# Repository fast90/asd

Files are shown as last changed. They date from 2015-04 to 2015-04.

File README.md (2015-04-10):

#Audio Switch Daemon

This circuit switches two audio sources, based on the status of a MPD-server running on a Raspberry Pi.

If MPD is playing the Raspberry Pi (INPUT 2) is switched to OUT.
When MPD stops playing OUT is switched back to INPUT 1.

# Library
Libbcm2835 is used for GPIO access. See http://www.airspayce.com/mikem/bcm2835/ for details.

# Schematic
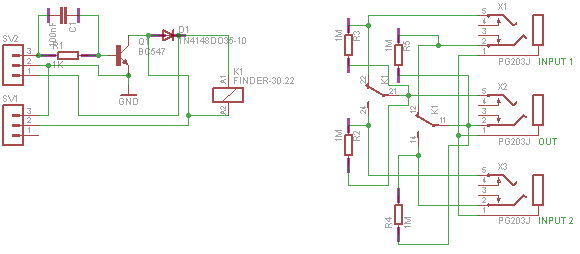
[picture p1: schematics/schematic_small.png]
Schematic


# Wiring
| Raspberry Pi Pin No. | Audioswitch Pin | Function |
|:---:|:---:|:---:|
| 8 | SV2 - 3 | GPIO 14  |
| 2 | SV2 - 2 | GND |
| 6 | SV2 - 1 | +5V |

SV1 can be used to connect a manual switch.

# Setup
Install the Library see http://www.airspayce.com/mikem/bcm2835/ for details.

If you are using a Raspberry Pi 2 you need to enable device tree support!

```bash
sudo raspi-config
```
```bash
->Advanced Options -> enable Device Tree
sudo shutdown -r now
```
Then type
```bash
./configure
make
make install
```

# Configuration & Usage
|  Option | Argument | Function | Default |
|:---:|:---:|:---:|:---|
|  h | |Show help | |
|  v | |Show version | |
| no-daemon | |Don't detach from console | |
|  p | <PinNumber>  |Change Pin | GPIO17 |
|  s | <SocketPath> |Change Path to socket |/home/pi/.mpd/socket|

```bash
asd -p 17 -s /home/user/.mpd/sock
```

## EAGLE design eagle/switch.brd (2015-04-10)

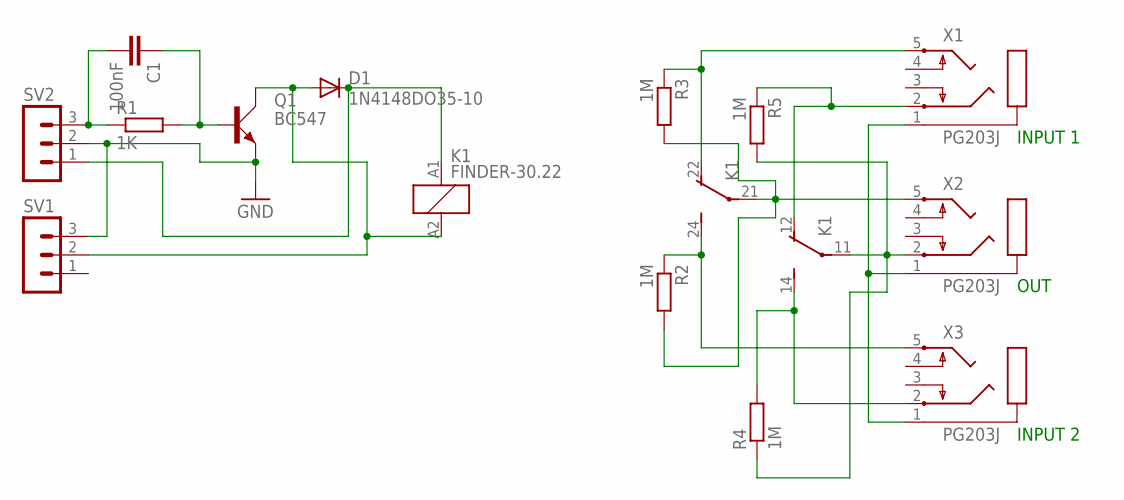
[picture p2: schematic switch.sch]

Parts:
C1: 100nF; C025-025X050
D1: 1N4148DO35-10; DO35-10
K1: FINDER-30.22
Q1: BC547; SOT54A
R1: 1K; 0207/10
R2, R3, R4, R5: 1M; 0207/10
SV1, SV2: MA03-1
X1, X2, X3: PG203J

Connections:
GND: Q1.E, SV1.3, SV2.2
unnamed: K1.22 (O), R3.1, X1.5
unnamed: K1.24 (S), R2.1, X3.5
unnamed: K1.11, R4.1, R5.2, X2.2
unnamed: D1.A, K1.A2 (2), Q1.C, SV1.2
unnamed: K1.12 (O), R5.1, X1.2
unnamed: K1.14 (S), R4.2, X3.2
unnamed: C1.2, R1.1, SV2.3
unnamed: C1.1, Q1.B, R1.2
unnamed: X1.1, X2.1, X3.1
unnamed: D1.C, K1.A1 (1), SV2.1
unnamed: K1.21, R2.2, R3.2, X2.5

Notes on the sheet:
OUT
INPUT 1
INPUT 2

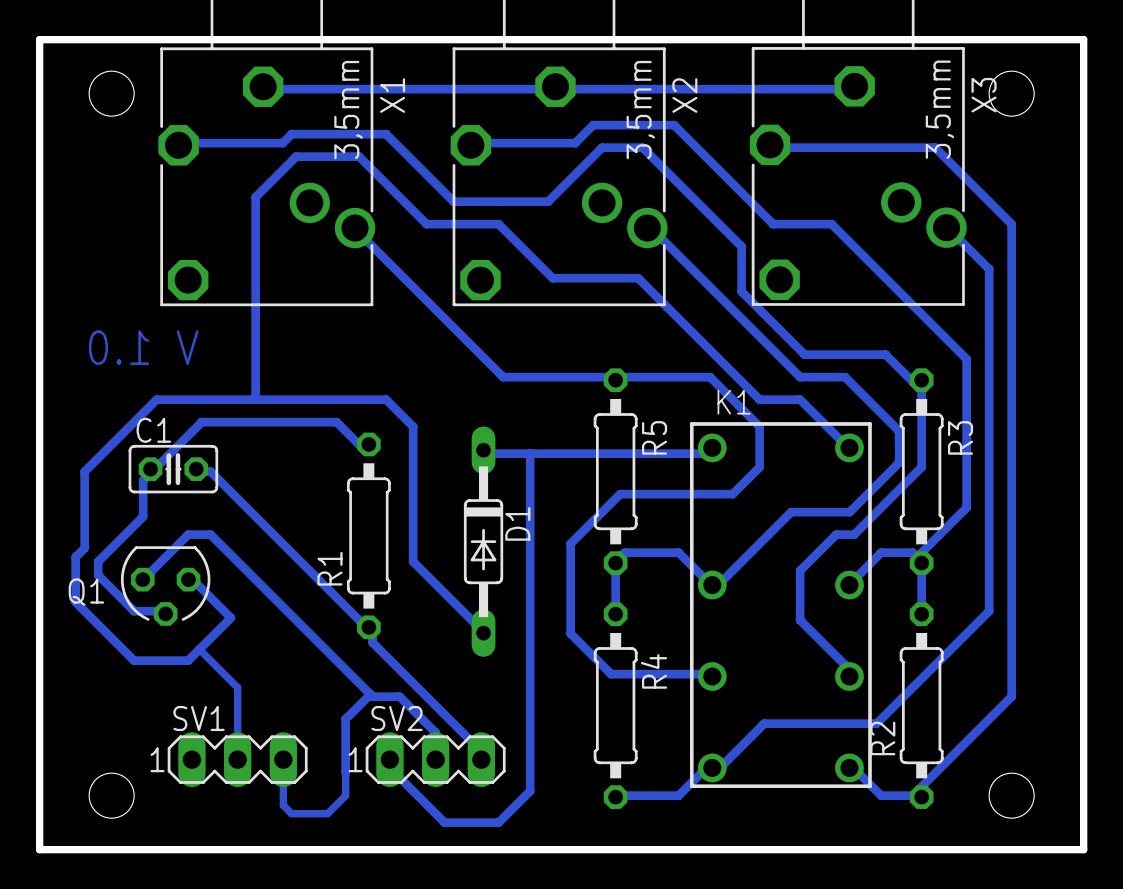
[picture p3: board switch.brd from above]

Board: 2 copper layers, 58.0 x 45.0 mm, 14 parts (0 on the bottom side), 12 nets.

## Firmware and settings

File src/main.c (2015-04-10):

/*
 * Controll Raspberry Pi GPIO based on MPD Status
 * Copyright (C) 2015  Fabian Stahl <fabian.m.stahl@posteo.de>
 *
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
 * You should have received a copy of the GNU General Public License
 * along with this program.  If not, see <http://www.gnu.org/licenses/>.
 */

#include <unistd.h>
#include <stdlib.h>
#include <stdio.h>

#include "gpio.h"
#include "daemonize.h"
#include "status.h"
#include "options.h"
#include "arguments.h"
#include "switch.h"



int main(int argc, char *argv[])
{
  /*Parse arguments*/
  parse_arguments(argc, argv);

  /*Daemonize*/
  if(daemon_flag > 0)
    daemonize();

  /*Setup GPIOs*/
  if(gpio_setup() < 0)
    {
      exit(EXIT_FAILURE);
    }

  /*Set initial state*/
  state = STATE_NORMAL;

  while(1)
    {
      sleep(1);
      switch_output();
    }

  return 0;
}

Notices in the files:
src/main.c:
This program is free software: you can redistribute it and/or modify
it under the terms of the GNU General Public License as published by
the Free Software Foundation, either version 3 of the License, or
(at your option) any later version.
